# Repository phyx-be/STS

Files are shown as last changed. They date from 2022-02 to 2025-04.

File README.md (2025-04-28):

# Space Shuttle Discovery
This small kit card style solder kit uses a CR2032 coin cell battery to power 3 candle-style flickering LEDs.
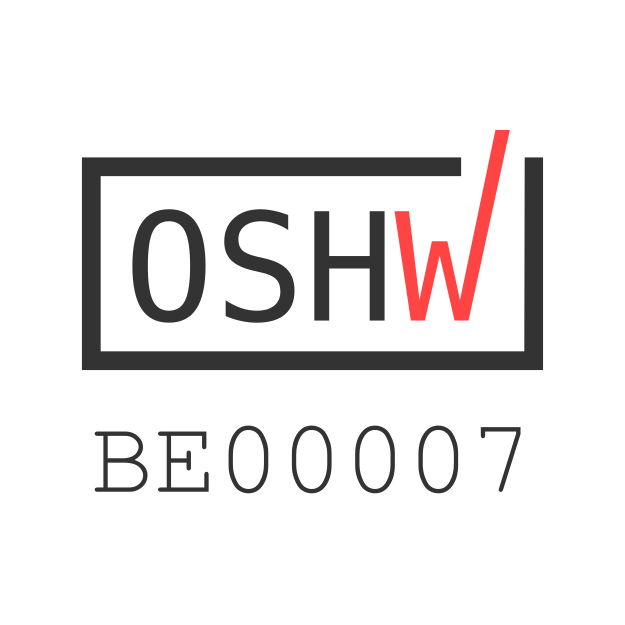
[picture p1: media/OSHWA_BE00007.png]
OSHWA (https://certification.oshwa.org/be000007.html)


## Get yours
The kit is available from various retailers like [Adafruit](https://www.adafruit.com/product/5414), [Pimoroni](https://shop.pimoroni.com/collections/all?vendor=Phyx) and [Stem Support](https://stem-support.be/) and in our own [Lectronz store](https://lectronz.com/stores/phyx). 
If you need a large quantity for events or educational purposes, the kit is also offered in bulk through [Stem Support](https://stem-support.be/) in Belgium or directly from us.

## Assembly instructions
- carefully depanelize the PCB by bending it
- optionally file or sand the rough edges
- pay attention to the orientation of the battery holder and the LEDs
- carefully bend the LED leads and solder them in place before assembling the plane
- slide the wings over the leg of the body
- pay attention to the polarity marks on the plane body and the baseplate
- solder the mechanical joints on one side first. This will allow you to make easy corrections when it's not perfectly perpendicular

A more detailed step-by-step assembly manual with pictures is available [on the Adafruit website](https://learn.adafruit.com/space-shuttle-discovery-solder-kit).

## REV 00
First prototype to verify the mechanical design.

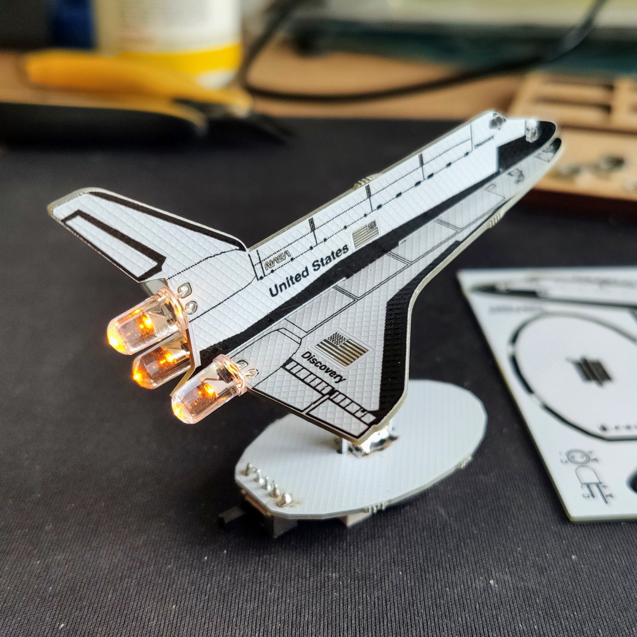
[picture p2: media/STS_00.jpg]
STS 00


## REV 01
Updated the mechanical design.

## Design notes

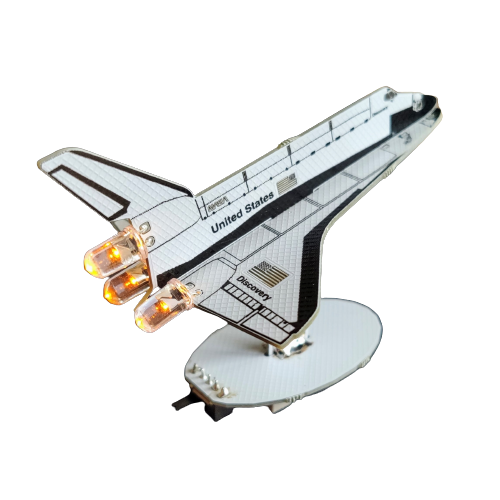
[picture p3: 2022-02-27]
media/STS_00_noBG.png

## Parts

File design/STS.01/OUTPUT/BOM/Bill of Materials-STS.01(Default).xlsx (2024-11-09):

Bill of Materials |  |  | STS
Project: |  | STS.01.PrjPcb
Revision: |  | 01
Variant: |  | Default
Creation Date: | 27/02/2022 | 12:15
Print Date: | 2024-11-09 | 14:32:20
Footprint | Comment | LibRef | Designator | Value | Description | Supplier 1 | Supplier Part Number 1 | Supplier 2 | Supplier Part Number 2 | Quantity
BAT_CR2032_KEY_1060 | CR2032 SMD Battery Holder | BAT # 20mm Coin Cell Holder Keystone 1060 | BAT1 | CR2032 | BAT # 20mm Coin Cell Holder Keystone 1060 | Digi-key | 36-1060-ND | LCSC | C70377 | 1
~~LED_5MM_RD~~ | ~~Default 5mm Red LED~~ | ~~LED Red 5mm~~ | ~~D1, D2, D3~~ |  | ~~LED Red 5mm~~ | ~~Farnell~~ | ~~2335725 ~~ |  |  | 0
LED_5MM_RD | 5mm candle flickering orange LED | LED Orange 5mm | D1, D2, D3 |  | LED Flame orange 5mm | AliExpress |  |  |  | 3
SK-12D07 | mini Switch 1 pole double throw right angle | SW 1P2T micro RA SK-12D07 | SW1 | SK-12D07 | SW 1P2T micro RA SK-12D07 | AliExpress | SK-12D07 | LCSC | C431548 | 1
 |  |  |  |  |  |  |  |  |  | 5
Approved |  | Notes

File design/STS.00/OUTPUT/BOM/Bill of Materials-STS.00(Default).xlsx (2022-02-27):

Bill of Materials |  |  | STS
Project: |  | STS.01.PrjPcb
Revision: |  | 00
Variant: |  | Default
Creation Date: | 27/02/2022 | 12:15
Print Date: | 2022-02-27 | 12:16:18
Footprint | Comment | LibRef | Designator | Value | Description | Supplier 1 | Supplier Part Number 1 | Supplier 2 | Supplier Part Number 2 | Supplier 3 | Supplier Part Number 3 | Quantity
BAT_CR2032_KEY_1060 | CR2032 SMD Battery Holder | BAT # 20mm Coin Cell Holder Keystone 1060 | BAT1 | CR2032 | BAT # 20mm Coin Cell Holder Keystone 1060 | Digi-key | 36-1060-ND | LCSC | C70377 |  |  | 1
LED_5MM_RD | Default 5mm Red LED | LED Red 5mm | D1, D2, D3 |  | LED Red 5mm | Farnell | 2335725 |  |  |  |  | 3
SK-12D07 | mini Switch 1 pole double throw right angle | SW 1P2T micro RA SK-12D07 | SW1 | SK-12D07 | SW 1P2T micro RA SK-12D07 | AliExpress | SK-12D07 |  |  |  |  | 1
 |  |  |  |  |  |  |  |  |  |  |  | 5
Approved |  | Notes

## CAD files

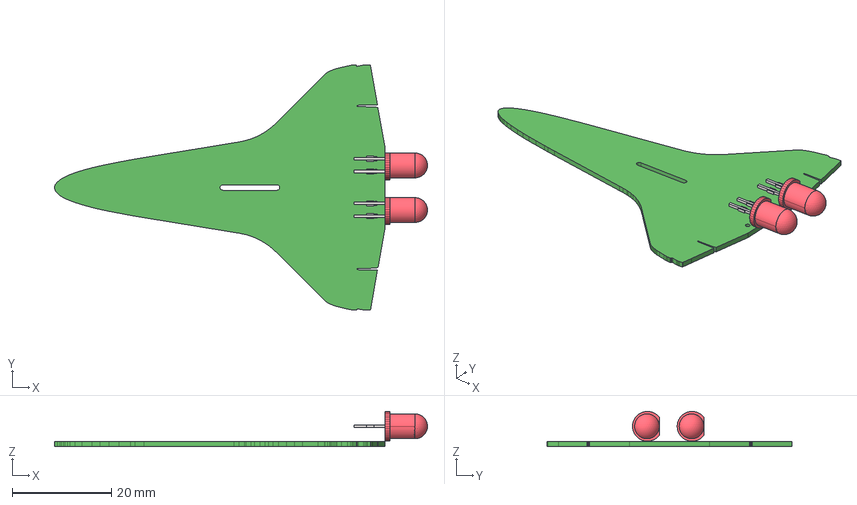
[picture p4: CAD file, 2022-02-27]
design/STS.00/STS_WINGS.00.step
75.2 x 49.5 x 7.10 mm
SW3dPS-LEDd5R_Extruded3 x 2
SW3dPS-LEDd5R_Extruded x 4
SW3dPS-LEDd5R_Cylinder x 2
SW3dPS-LEDd5R_Extruded4 x 2
SW3dPS-LEDd5R_Sphere x 2
SW3dPS-LEDd5R_Extruded2 x 4
SW3dPS-LEDd5R_Extruded1 x 2

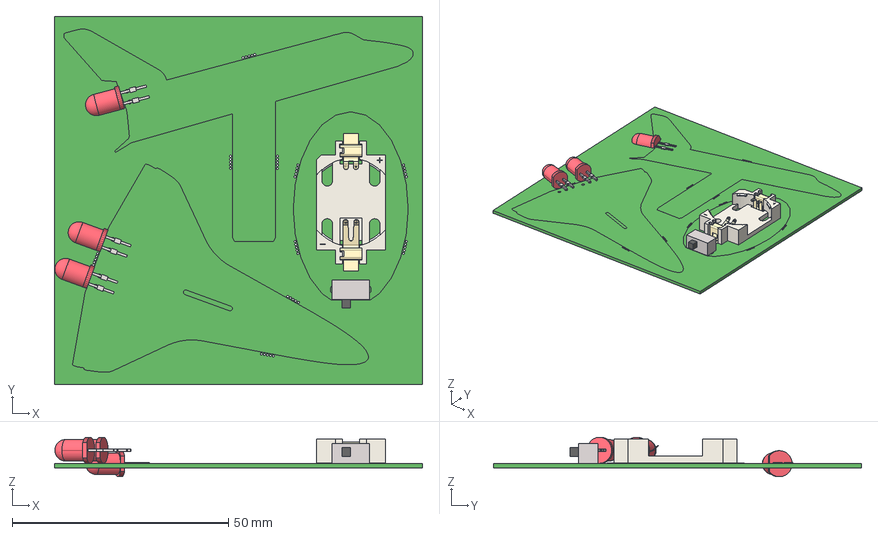
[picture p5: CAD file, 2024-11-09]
design/STS.01/STS.01.step
85.0 x 85.0 x 9.12 mm
SW3dPS-LEDd5R_Extruded3 x 3
SW3dPS-LEDd5R_Extruded x 6
SW3dPS-LEDd5R_Cylinder x 3
SW3dPS-LEDd5R_Extruded4 x 3
SW3dPS-LEDd5R_Sphere x 3
SW3dPS-LEDd5R_Extruded2 x 6
SW3dPS-LEDd5R_Extruded1 x 3
Extruded x 2
keystone-PN1060

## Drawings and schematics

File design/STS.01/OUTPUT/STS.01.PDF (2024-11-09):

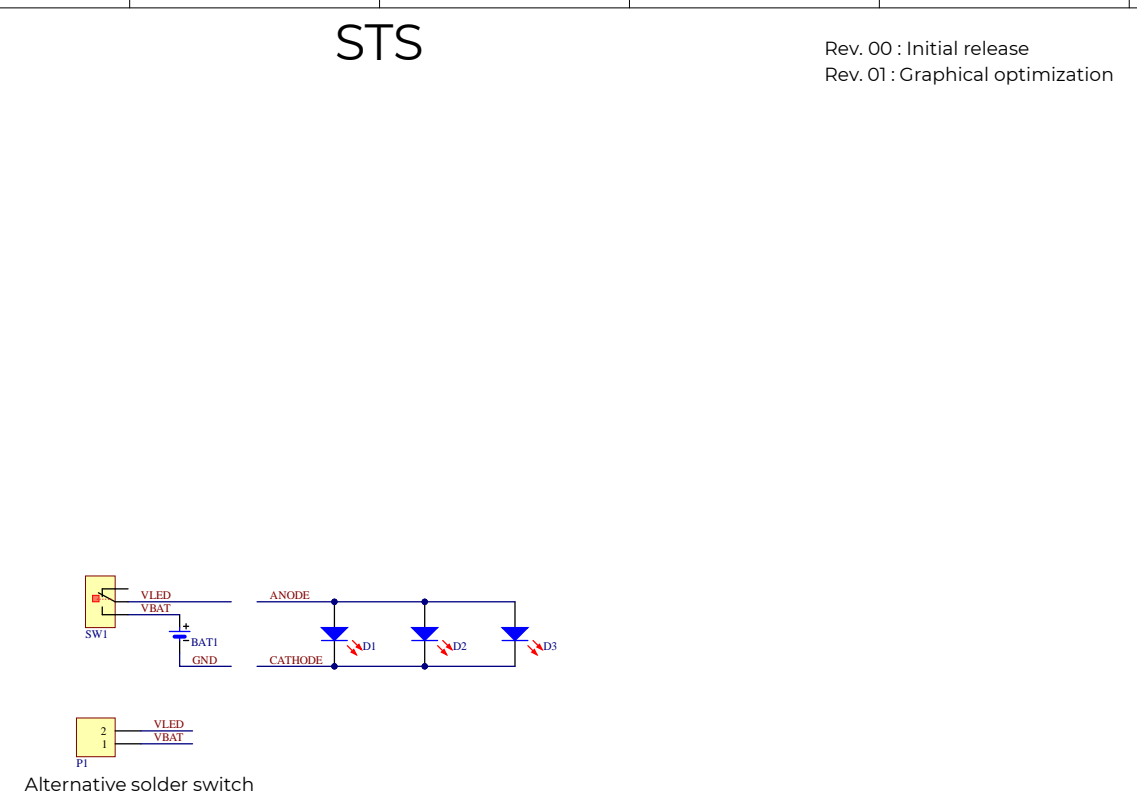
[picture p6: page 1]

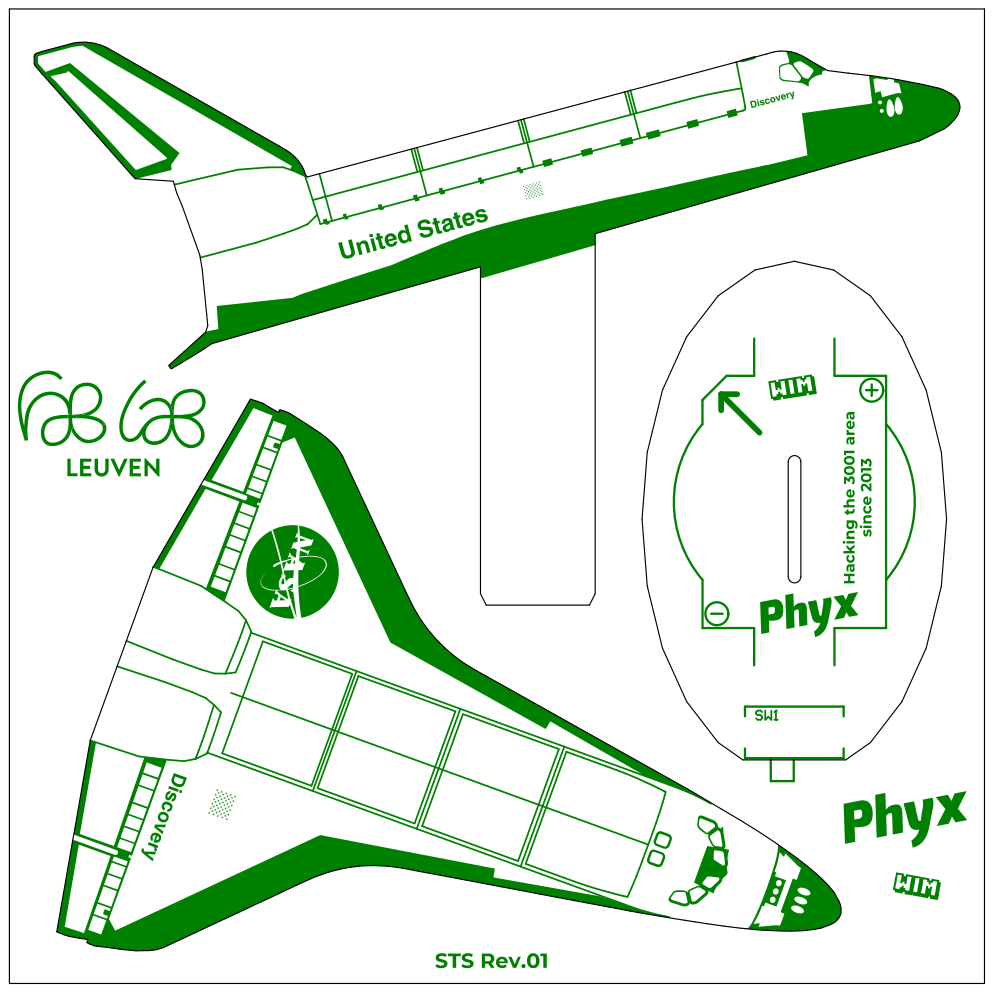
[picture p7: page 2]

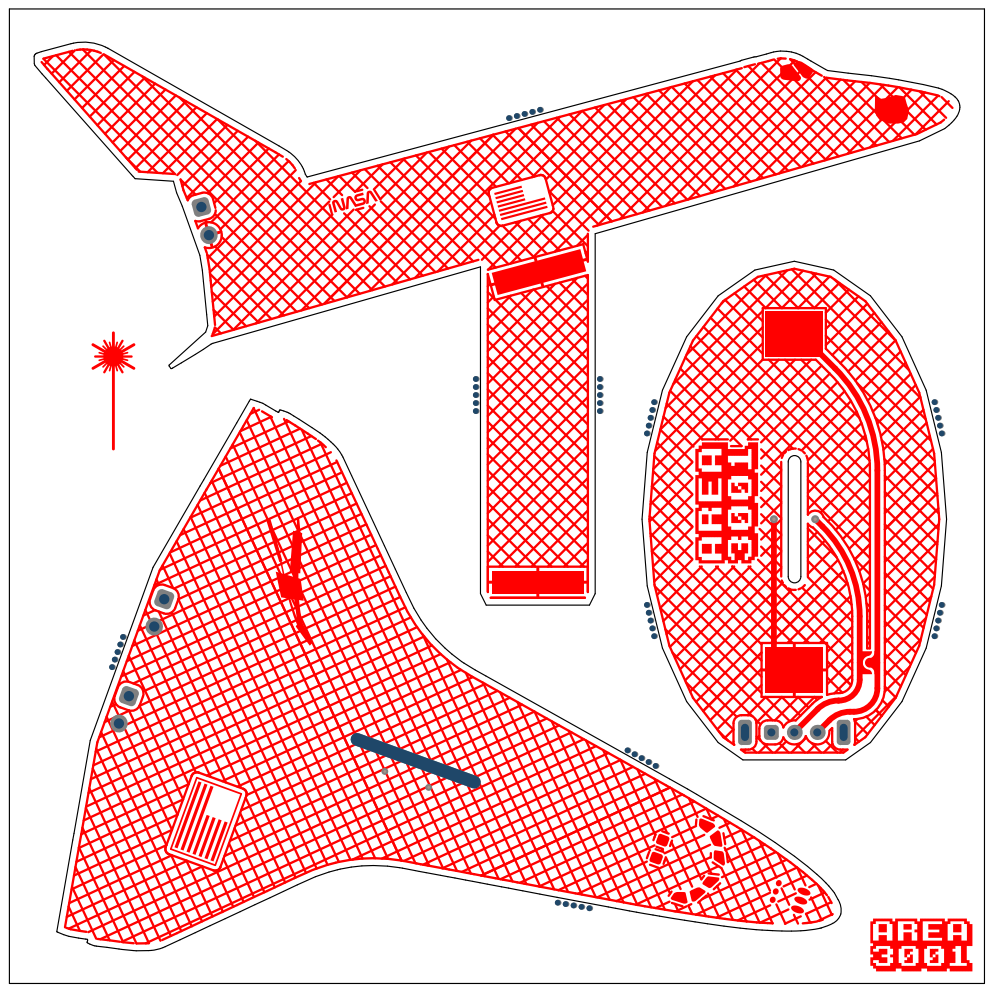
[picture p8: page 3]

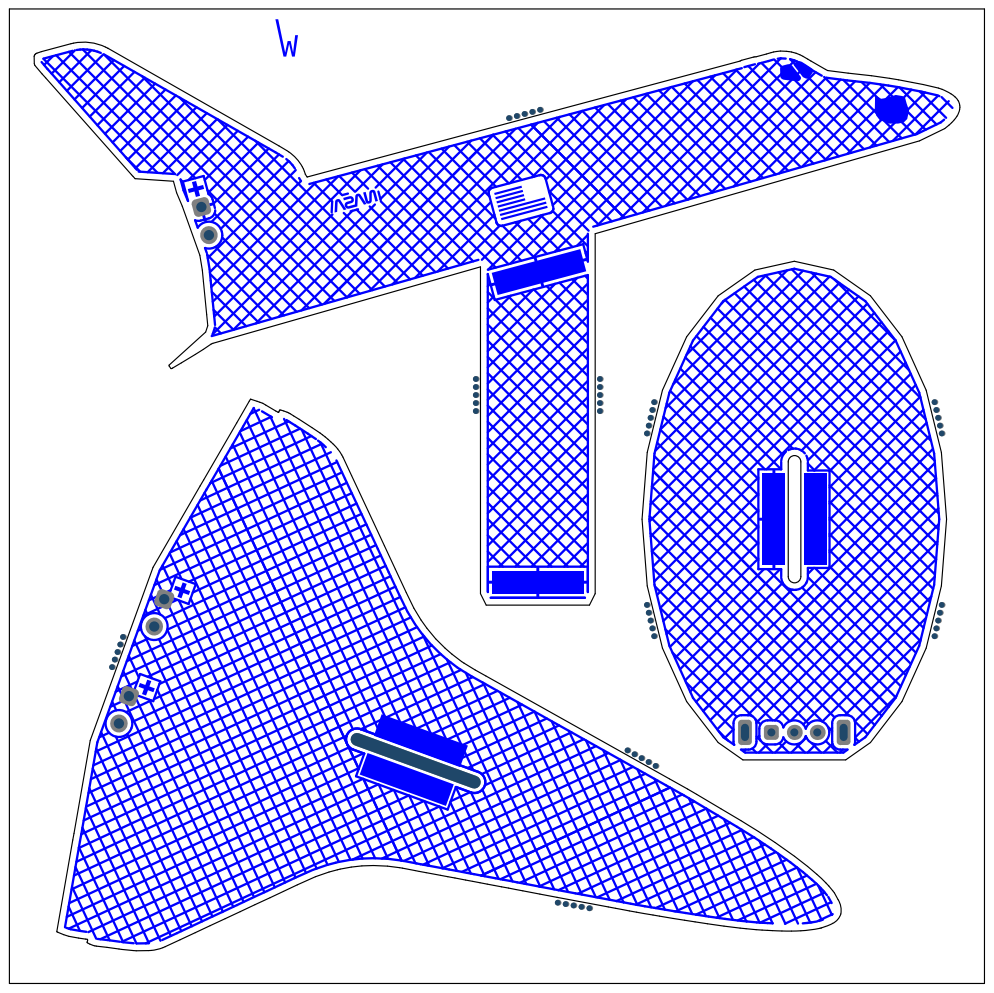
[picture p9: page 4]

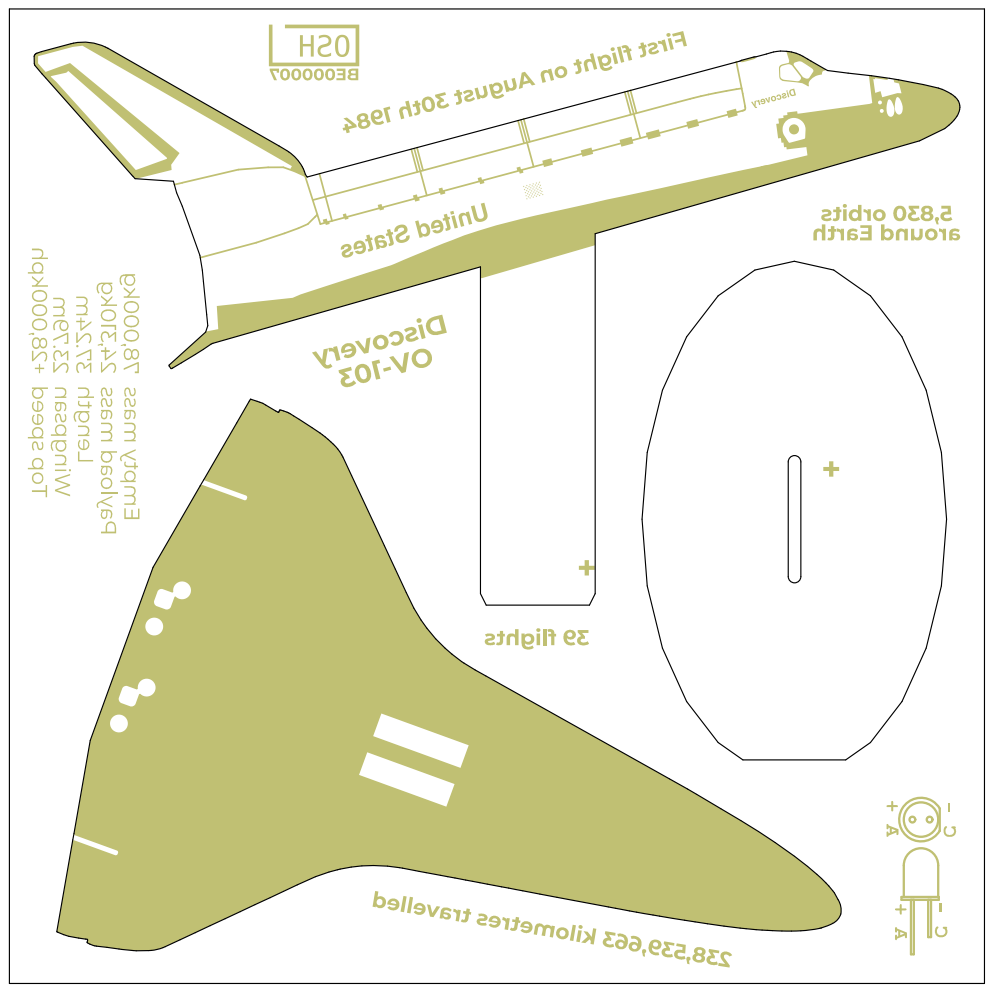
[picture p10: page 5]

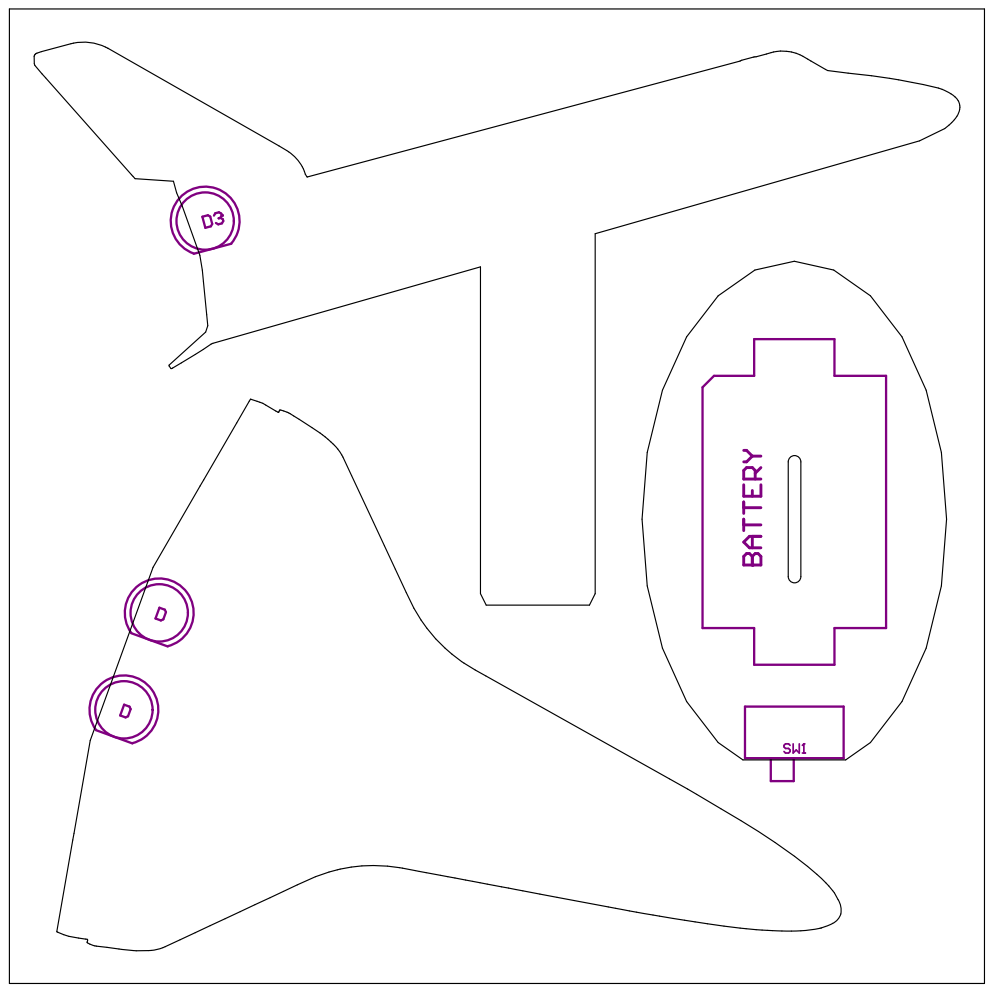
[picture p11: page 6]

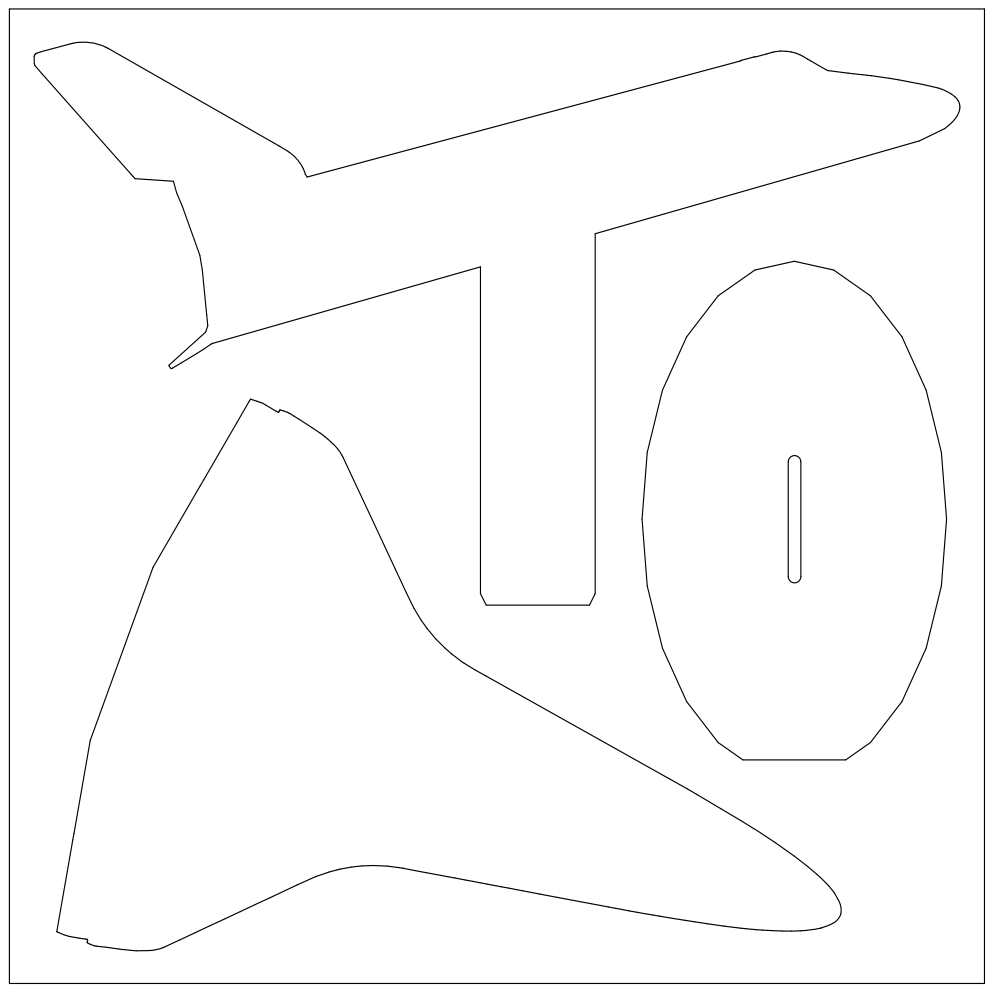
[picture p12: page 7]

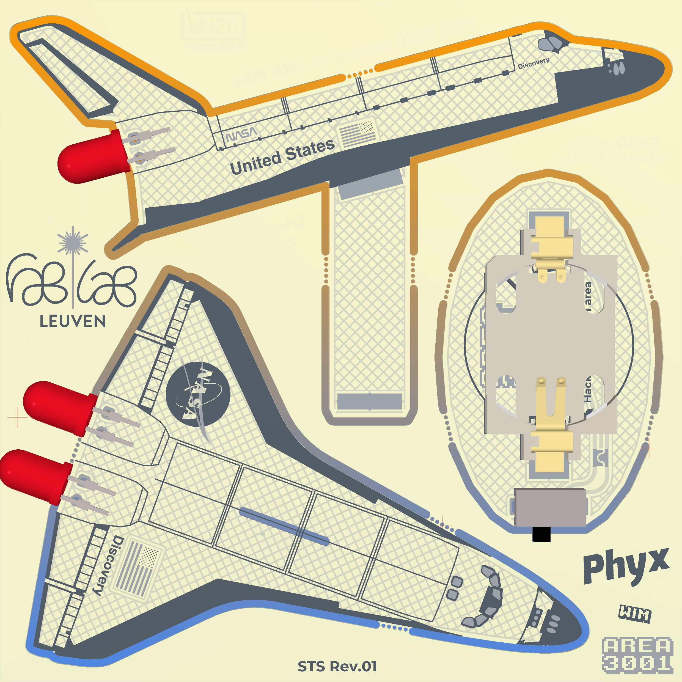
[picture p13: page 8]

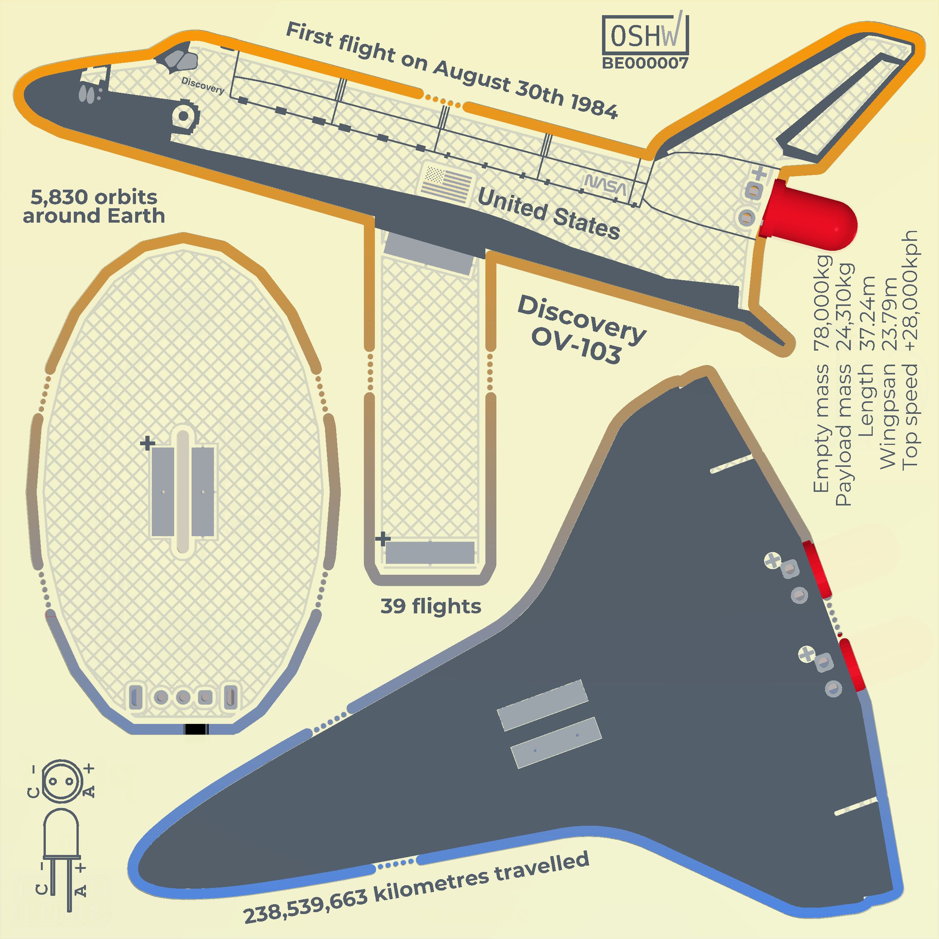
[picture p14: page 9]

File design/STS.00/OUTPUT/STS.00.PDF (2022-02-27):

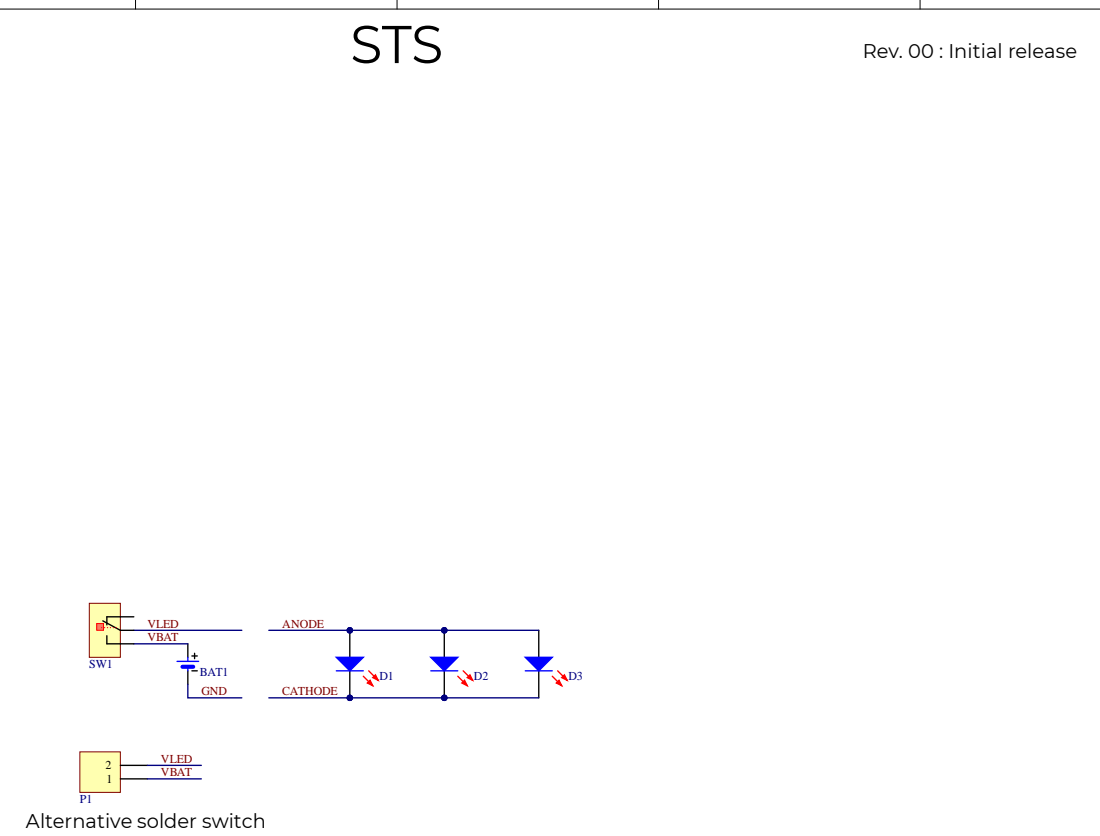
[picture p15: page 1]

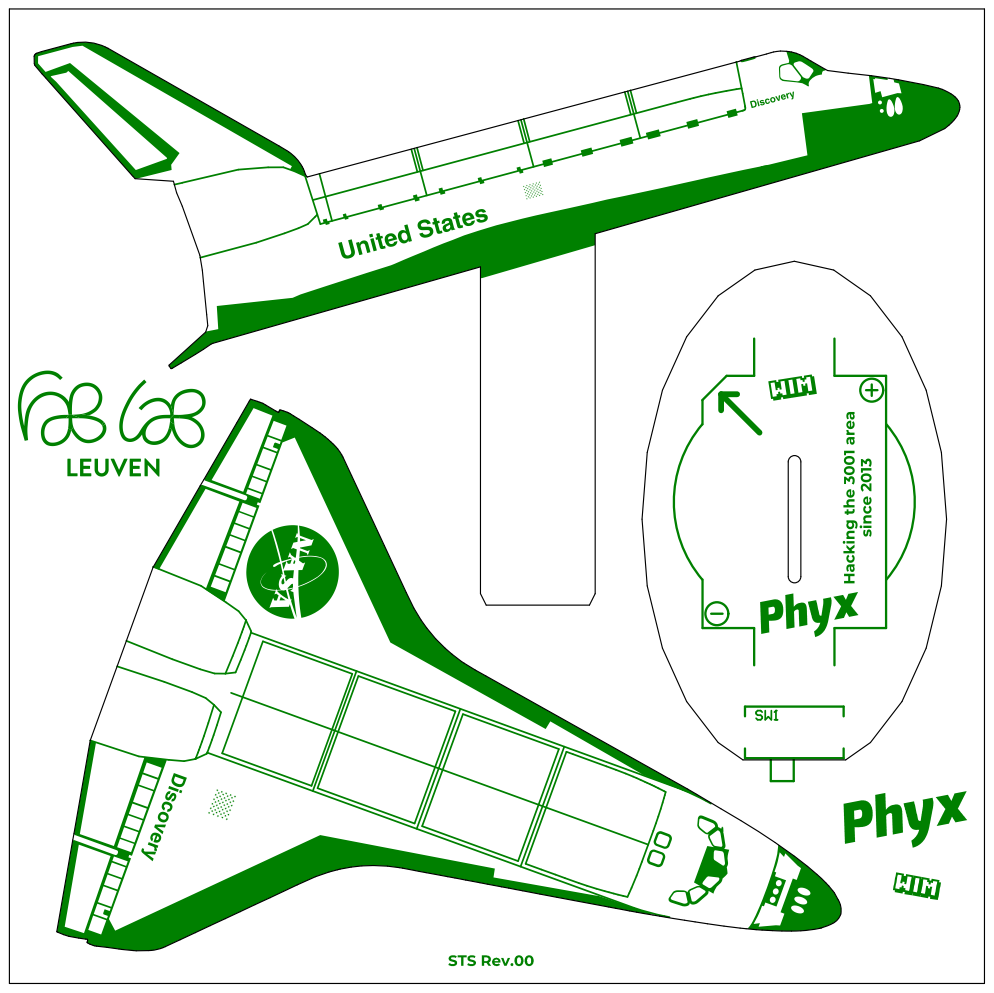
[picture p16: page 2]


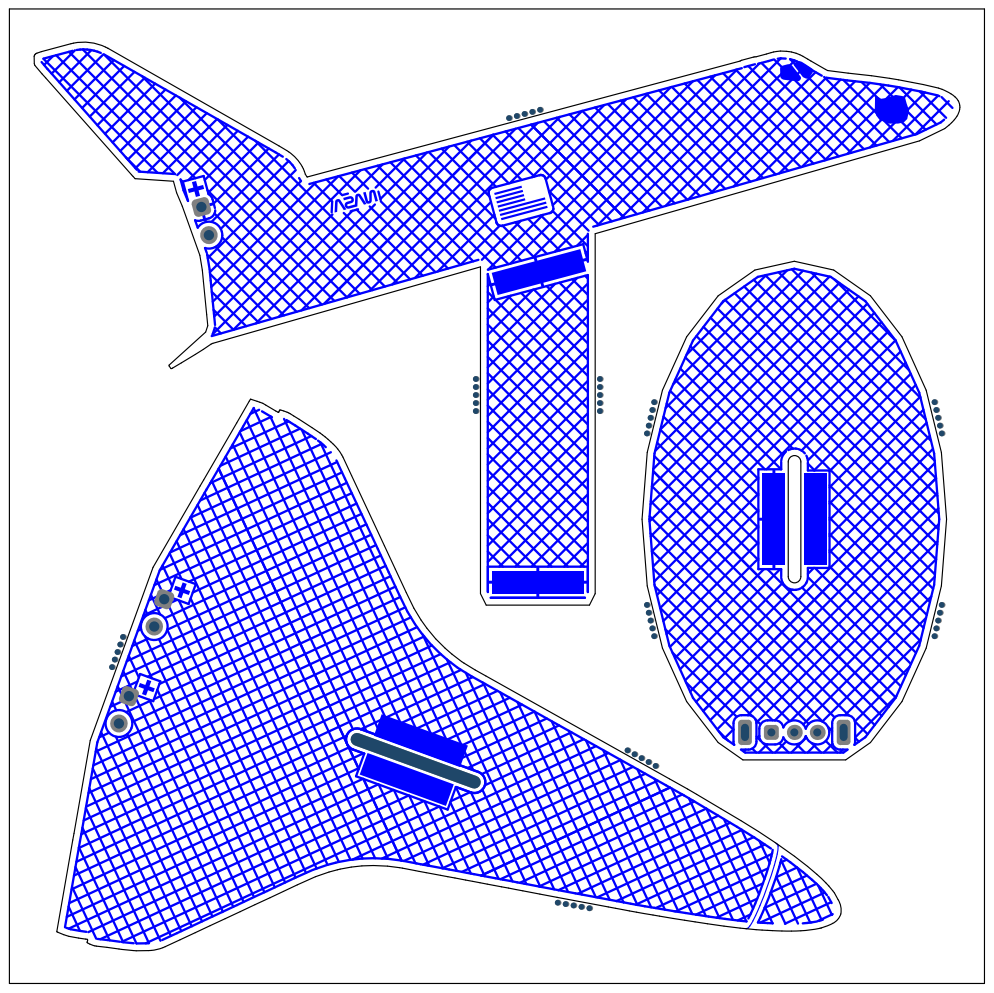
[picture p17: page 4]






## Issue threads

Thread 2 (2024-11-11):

LED type

Sokoloft, 2024-11-11:
Hi!

Do you have a data sheet for the specific candle LED's used in this kit? I bought one off adafruit last year or so and I use it with older CR2032's I pull out of computers, keyfobs etc. However stock of those is dwindling!  I do have a bunch of old 9v batteries kicking around that have anywhere from 5-7v. Would like to rig up a couple dupont connectors, just unsure what resistor I would want.

Thanks. Great little kits btw. Love the discovery one I have.

Brubacker, 2024-11-12:
Thanks for the compliment!
Sadly there is no datasheet available for this part, the manufacturer states 3.0~4.5V and 20mA (but they don't differentiate between blue, green, red, orange or white versions...)
So to be safe I've used a 3.0V LDO on my mini Airport to be able to power them from USB.
https://lectronz.com/products/fs-plate-00
The LDO I selected is te XC6206P302MR which you van get from LCSC : C347375, C479054 or C296234

I also made a smaller version of this to power 1 plane with 2 AAA batteries or USB :
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
I'll release those files soon on github.

Sokoloft, 2024-11-14:
ooo nice, that power board seems great!

I'm looking into LDO's now and the `LM1117-3.3` has a 4 pin sot variant. Might be able to tweak that board to accept both IC's in case a user wants to provide a bigger voltage. From what I see the `XC6206P302MR` can only take a maximum voltage of 6.5v.

Thanks!

Sokoloft, 2024-11-14:
Turns out I have some esp32 cams I'm not using that has one of those `LM117-3.3` on it. Took it off, used a 10uF ceramic input and 100uF electrolytic on the output. The picture is rough but its working!

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

Brubacker, 2024-11-14:
Perfect solution!

Closed 2024-11-14.

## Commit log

2022-02-27 Rev 00 commit
    Rev. 00 comitted.
    [Bill of Materials-STS.00(Default).xlsx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]
2024-11-09 added Rev.01 design files
    [Bill of Materials-STS.01(Default).xlsx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]
